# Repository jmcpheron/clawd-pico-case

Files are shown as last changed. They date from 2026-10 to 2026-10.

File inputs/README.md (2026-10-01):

# Inputs

Design files contributed by people working on this repo, kept byte-for-byte as
received. They are evidence of where a design came from, not build sources:
the parts are rebuilt in `cad/` from rows in `MEASUREMENTS.md`, and the
rebuild is checked against these files. Each file's origin, licence and
SHA-256 are logged in `PROVENANCE.md`.

| File | From | Rebuilt by |
|---|---|---|
| `2026-10-01-jason-pico-spacer.step` | Jason McPheron, Onshape, his calipers | `cad/pico_pin_spacer.py` (rows JS-*) |

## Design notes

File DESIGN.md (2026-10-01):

# Current: V3 fitted shells

J2 socket-first trial: preserve J1 exterior; roundØ3×1 deep then existing
2.01 square×2 deep, exactly as Austin requests. Print cap only before lowering
lid. Pending lowered-lid/hole-centre changes must not alter old print files.

SUPERSEDED by V3-FLAT: whole outer face atz5.1, print FACE DOWN, no supports
or raft. Austin explicitly allows greater screen depth for this trial.
Builder cad/v3_flat.py; reuse button/joystick geometry; lid-only correction.
See JOYSTICK-REVIEW.md for current status; upright plan below is historical.

Complete review and evidence: JOYSTICK-REVIEW.md. Builder cad/v3_fit.py.
Reuse V2 button caps and unchanged J1 joystick; only base/lid print.
Closed V2-aligned USB aperture, no fin; retain pry/reset. Low screen side
rails, local J1-height joystick roof and V2-height button deck. Upright lid
print intent, no supports/raft; mandatory slice review. Historical D7/D8
below are rejected designs, not the current print candidate.

# Historical V3 low-lid revision — D7/D8

Original MIT geometry from this repository's hardware measurements and
Austin's feedback. No external case geometry. Review only, no print approval.

Hard constraint: lid top is glass top +1 mm, z3.05. No joystick collar or
uniform case raise. The rejected tall draft remains saved in v3-review-1.

D7 side retaining tabs cleared5 degrees but failed16 ten-degree lid cases;
that unsuccessful experiment is saved in commit2587340.

D8 uses one rear arm/heel on the joystick cap. The heel is behind the PCB
edge, allowing downward tilt into a local interior pocket, without changing
case height. Earlier full-case4010773 lower socket/neck remain unchanged.
V2 ball diameter7 and small top print flat remain. The cap is still installed
before the lid. The rear heel's thin sections need slicer and strength review.

Button retaining wings now sit beside the switches, below the plunger tops.
The central underside contacts each plunger at measured z2.61. Outside cap
footprint and1.8 mm protrusion remain. Flat top-down printing is planned.

Keep V2-aligned closed USB port, no external lid fin, successful pry notches
and bottom access. Changes and all trial coordinates are recorded in
MEASUREMENTS.md. Required motion scenarios include the full10 degrees,
presses, both pivot assumptions and cap/base/PCB clearance. Inherited
socket/neck versus guessed metal-body collisions remain disclosed.

See reports/2026-09-25-low-lid-experiments.md. Browser review comes before
printing, and no new print artifacts have been produced for this revision.
# J1 isolated joystick test — 2026-09-25

See JOYSTICK-REVIEW.md for the complete current review packet. Original
round-lip cap plus hand-held lid gauge only; D8 rear arm rejected. J1 preserves
the selected V1 socket, has known10-degree motion failures, and is not sent
to the printer. Full-case geometry is unchanged.
## J3 / L1 trial — 2026-09-25

Widen round socket to Austin's 3.50 × 1.10 mm; keep square 2.01 × 2.00 mm
and exterior unchanged. Lower whole flat face 0.90 mm to z4.20, pocket roof
to z3.50. Existing buttons limit further lowering: 0.64 mm roof now remains.
No local boss, supports, USB fin, new base or new buttons. Lip height z2.45
is Austin's estimate for visualization, not proven seating. Iteratively find
motion limit then back off. Full details in JOYSTICK-REVIEW.md.
## L2 / J2 authorized physical trial — 2026-09-25

Move L1 upper roof down 1.00 mm, retaining roof thickness. Keep lower wall
geometry through original glass-clearance height and union translated upper
geometry; preserve contacts, mating skirt and snaps. Face z3.20, joystick
underside z2.50, button underside z2.56. Same base/buttons; exact J2 socket.
User accepts possibly unsuccessful fit; predicted overlaps remain in report,
not suppressed or counted as passes. Print face down with no supports/raft.
## L3 opening correction — 2026-09-25

L2 failed physical closure. Restore L1 thickness/height/pockets and shift only
round opening 1.00 mm toward LCD (CAD negative Y). Fill old throat crescent,
recut at new centre; retain 8 mm diameter and existing lip cavity. No base,
button or joystick changes. Print lid only, face down, supports/raft off.
## L4 alignment refinement

L3 physically overshot. New aperture centre is original X+0.30, Y-0.50:
halfway back from L3 and slightly photo-up with LCD on right. Keep diameter,
height and lip pocket unchanged. Photo-up magnitude is explicitly a trial
choice, not a calibrated measurement. Prepared lid only, not dispatched.
## S1 stronger walls / lower seam — review before printing

Austin's IMG_0834 shows exterior flexible bands and catch windows; he reports
bending during print removal. Replace these with continuous walls and blind
internal detents. Move visible seam to one-third of total height from bottom.
Make walls 3 mm by growing outward, preserving internal board clearances and
fitted control roof heights. A continuous thick perimeter/deeper walls are
intended to improve stiffness without lowering the control pockets again.

Joint uses 3 mm overlap, 1.4 mm socket wall, 0.2 mm gap, 1.4 mm tongue;
small bidirectional ramp catches allow removal without exposed flexible slots.
Minimum exterior skin at blind catches is 1.05 mm. One pry notch remains.
Actual strength, release force and cycle life require testing.

Transfer board support to two base-carried internal rails because the original
wall shelf would otherwise belong to the upper shell and obstruct assembly.
Retain USB port/reset location; extend outside cable recess to compensate for
added wall thickness. L4 opening offset retained. New matching shell pair;
does not fit old base. Interactive review requested; no printer dispatch.
## S2 closure and tactile refinement

S1 field feedback: loose vertical joint and indistinct button tops. Replace
base only: preserve body/rails/ports, swap symmetric triangular detents for
deeper catches with flat holding face, short vertical nose and insertion ramp.
Use existing lid-pocket lower edge to reduce nominal axial travel to0.04 mm;
projection0.50 consumes0.30mm socket flex and leaves0.05mm recess spare.
No claimed FDM accuracy or tested retention force. Small catch overhang needs
slice review. Keep existing lid/pry notch; no new exterior slots.

Caps retain V2 interface, gain0.50mm height and1.20mm rolled top edges to
separate finger contact areas. No change to button spacing or flange height.
Print five parts in PLA; defer PETG/colors until fit iterations finish.
## V1.0 production — final nudges

S2 passed Austin's hands-on test, so the design is frozen apart from three
0.25 mm nudges. Each one moves an opening and keeps its size, so nothing else
in the fit changes. Joystick throat: +y, away from the LCD. It uses L4's
method: fill the old throat through the roof, then cut the new one. The pocket
underneath does not move. USB-C aperture and plug recess: +z. Both stay under
the seam, so the lid needs no change there. The bottom clearance to the
modelled shell drops to 0.10 mm, which is fine because the photo shows the
real receptacle sitting high. Reset hole: -y. Each opening is refilled only
inside the original wall or floor before it is recut, and a check shows
nothing else changed. The buttons and J2 are byte-identical to the tested
parts. PETG shrinks differently from PLA, so the first PETG set is also a
fit check.
## V1.1 USB-end spacer

The v1.0 PETG test showed the stack sliding along the case, and it lines up
best pushed toward the buttons. The holes are therefore right for that
position, so the fix holds the board there and leaves every opening alone.
The USB-end stop face moves 1.0 mm inward: Austin felt about 1.2 mm of play,
and 0.2 mm is kept free so a rigid PCB cannot bind. The model predicts 0.6 mm
of play, so the real board or print differs from the model; his hands win.
The rails would block a full-width lid wall, so the stop is split in two. The
lid gets a lip between the rails that catches the LCD PCB edge; its 45° top
prints face-down with no support. The base gets end stops on top of the rails,
so the board is located before the lid goes on. The USB plug already works
with the board pushed this way, so the plug recess is unchanged.
## V1.3 short USB end (replaces the V1.1/V1.2 spacers)

The spacer added parts (a lid lip and base stops) and still needed both
halves reprinted. Moving the end wall in does the same job with less: the case
gets 0.5 mm shorter, there is no inner lip, and the USB plug sits 0.5 mm closer
to the port. The whole end is rebuilt from the moved datums, so the corners,
the tongue and socket, the rail ends (0.25 mm gap kept), the USB slot and the
plug recess all follow. Everything else is unchanged from v1.0, and a check
confirms that.
## J10 joystick set — 2026-09-29

A direction push on some devices clicks twice. The flange edge behind the push
rises into the lid underside, pivots there and drives the stem down into the
centre switch. Austin wants a joystick-only fix, so the lid is unchanged.
Four caps, numbered I-IV on top, each keep J9's socket and top and change only
what sits under the lid. I and II swap the full disc for four tabs. A tab off
the push axis rises less than the disc rim directly behind the push. I puts
them on the socket diagonals, II on the flats; the stem's turn on the board
is not measured, so one of the two lands on the diagonals. III and IV ride
0.2 lower for more room under the lid, at the risk of a stiffer press (why
J5 raised it). The model gives the tabs 2-3 degrees more tilt before the lid
is touched; the true tilt and seating are unmeasured, so the print decides.
Numerals are engraved, not raised, so the top still feels flat.
## J11 square flange — 2026-09-30

J10 failed: tabs reaching 0.6 past the hole slip through it. Austin's
direction: keep J9 and make its flange a square, thin toward the four push
directions with the corners on the diagonals. The edge behind a push is then a
flat side, which rises less than the old disc rim; the corners sit off the
push axes and still hold the cap in the hole. Two sizes (8.0 and 7.2 across the
flats) and both turns against the socket, because the stem square's turn on
the board is not measured. The pair whose flats face up/down/left/right is the
right turn. A flange that drops lower past the switch body is deferred: it
needs the body height, and it would stop the underside printing flat.
## J12 ride height on J11-III — 2026-09-30

J11-III cured the double click, but the centre press is hard to get without a
direction: the cap sits too low on the stick. J12 raises it the J5 way, with a
shallower round mouth, in four 0.1 steps (V-VIII). Riding higher gives the
press room but lifts the flange toward the lid again, so the set spans both
ends: VIII is back near J9's lid clearance in the model. Austin picks the
lowest one whose centre press is clean.
## J13 split press room from lid room — 2026-09-30

Ride height alone trades press room against lid room, and the working window
sits between VI and VII. The underside of the cap sets press room; the flange
top, where it sits under the lid, sets lid room. J13 thins the flange only
under the lid (0.24 from the hole edge out), so a cap can ride VII-high with
more lid room, and the underside still prints flat on the bed. A smaller square
can't help: its corners must reach past the hole. Round discs just past the
hole close the see-through gap the square leaves; in the model only the 8.6
disc beats VII, and it overlaps the hole by 0.3, so it may be loose. Letters
replace numerals.
## J14 stick fit on J13-O — 2026-09-30

O won J13 on a rough print. J14 prints it clean in three grip sizes around
its 1.90 square (1.85 / 1.90 / 1.95), everything else identical, so the next
test shows both whether O repeats and which grip holds best. Dots replace
letters because small engraved letters print as blobs.
## J16 hard stop and pull-out flares — 2026-09-30

J15's round mouth let the cap slide over the stem's base lip when pushed hard,
and its 0.3 overlap let a hard pull take it out of the lid. J16 cuts the square
grip all the way to the bed face, so the lip stops the cap, and adds four
narrow thin flares on the diagonals. The flares must stay short and thin:
material far out under the lid is what gets caught when the cap tips (the
8.6 disc edge slides into the hole instead), so the chosen flares keep VI's
lid room in the model while reaching 0.8 past the hole.
## J17 gradient on J16 — 2026-09-30

Bigger tabs hold the cap in the lid but get caught under the lid when it tips;
a shallower hole gives a better centre press but lifts the flange toward the
lid. Both push the same way, so J17 walks one path from J16 (tested clean) to
a cap the model is sure double-clicks, in five steps. Austin picks the step
with the best hold and press that still clicks clean.
## Jason's Pico pin spacer and its I2C variant — 2026-10-01

Jason's spacer is a 1.0 plate between the header rows with square-holed tabs
over chosen pins. It is rebuilt from rows rather than imported, so every
number traces to MEASUREMENTS, and the rebuild is checked equal to his STEP.

- On the datasheet grid: his caliper positions (17.70 × 48.20) are close to
  the 2.54 grid (17.78 × 48.26). Snapping keeps every added pin exactly on
  the pin it is meant for, rather than letting caliper rounding add up.
- Pins 6 and 7 share one tab: they are 2.54 apart, less than a 3.3 tab.
- Pins 36, 38 and 40 keep separate tabs, so pins 37 and 39 pass through the
  1.78 gaps. Those junction fillets are r 0.8, because two r 1.0 fillets
  need 2.0.
- With the extra tabs the part only fits one way round, but it would still
  slide onto pins backwards or upside down. A dot by pin 1 and an arrow to
  the USB end on the top face show which way it goes.
- Kept as his: the sharp corner where the plate end meets a corner tab, the
  r 1.0 tab corners, 1.3 square holes, 1.0 thickness.

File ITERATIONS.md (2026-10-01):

# Design and print iteration register

## J2 stepped joystick socket — 2026-09-25

cap only, unchanged J1 exterior, deeper round-to-square bore per Austin.
Source cad/joystick_j2.py; STL stl/joystick-j2; checks renders/joystick-j2.
Physical seating trial precedes lowered lid/hole-centre adjustment.

## V3-FLAT — 2026-09-25

Correct upright-print failure: uniform outer lid facez5.1, face-down STL,
supports/raft OFF,699 checks. Existing buttons still1.3 mm proud. Lid only;
no cap/base reprint. Sources cad/v3_flat.py, artifacts stl/v3-flat and
renders/v3-flat; print log prints/2026-09-25-v3-flat.md. Austin explicitly
allows whole-face height increase for fitting. Upright revision preserved.

Every saved design revision belongs in git with its original CAD, generated
STL/STEP files, rationale, evidence and validation results. Print jobs must
reference an immutable commit/tag and record slicer settings, artifact hashes,
delivery/start status and the eventual fit result. Never replace a failed
version's history with a corrected version or describe a queued job as printed.

## Historical designs (2026-09-24)

## Current: V3 fitted shells — 2026-09-25

Builder cad/v3_fit.py; files stl/v3-fit and renders/v3-fit. Only two shells.
V2 buttons and J1 cap reused without change.697 required checks, inherited
J1 motion uncertainty retained. JOYSTICK-REVIEW.md is the single review
handoff. Dispatch recorded in prints/2026-09-25-v3-fit.md. Upright lid needs
operator slice review before start; no supports/raft authorized.

## Historical designs (2026-09-24, continued)

| Commit | Iteration / change | Print evidence |
|---|---|---|
| `30ecec9` | First original board proxies, snap case, caps and viewer | No recorded result |
| `9260716` | Correct USB orientation to joystick end | No recorded result |
| `f178c19` | Square flanged button caps and individual holes | No recorded result |
| `6469436` | Print-oriented exports | Test 1 source; request logged at `752fcb4` |
| `f3eb689` | Thicker tongue, Ø10.5 joystick opening | Intermediate lid revision; see historical REPORT.md |
| `29e74e1` | Working snap windows/wedges, corner and documentation audit | Intermediate corrected geometry |
| `4010773` | Test 2: Ø12 joystick opening, neck/disc cap, USB envelope/recess, two pads | Request logged at `28f6932`; fit result pending |
| `prototype-r4` tag | R4: mating gap/flexible bands, USB insertion channel/fin, sloped shelves, four pads, cap clearance fixes, 171 geometric checks | Test 3 submitted to HTTP inbox; IDs and pending result in its log |

Setup, measurement and report commits are also preserved in the full git
history. This register identifies meaningful design states; it does not imply
that every intermediate state was physically printed. Earlier unsaved edits
cannot be reconstructed as separate revisions.

## V1 feedback / R5 checkpoint

Austin identifies the photographed first-principles case as V1; its exact
print commit is not established. Three photos and five requested changes
are saved in `prints/2026-09-24-v1-feedback.md`.

Tag `r5-wip-joystick-pry`: captive ball joystick and two pry notches;
273 CAD checks pass. Not submitted; not ready to print. USB-C and
rectangular/taller buttons and bottom button access remain pending.
Earlier history is preserved.

## Artifact reproducibility

## V2 print candidate / completed R5

Tag `prototype-v2`: completes all five V1 requests. Adds scan-derived bottom
button hole, rectangular/taller buttons, higher/tighter USB-C; retains
checkpoint joystick and notches. Includes measurement script/overlay,
mesh degenerate-facet removal, geometry checks, STL/STEP, preview and hashes.
Print status and eventual results: `prints/2026-09-24-v2.md`. V2 is not a
physical-fit certification. Older WIP remains saved under its own tag.

## Hash records

## V3 browser review — 2026-09-25

Tag `v3-review-1`: original4010773 lower joystick interface, V2-sized ball
with printing flat, tapered inside lip, uniformly flat lid4 mm higher, longer
button stems, closed USB base port without fin. V2 USB alignment retained.
Browser viewer includes orbit, explode, part toggles and shell transparency.
See `reports/2026-09-25-v3-review.md`; requires Austin's approval before print.
No printer submission. Geometry/tag are a review checkpoint, not print success.

## Hash records (all revisions)

## V3 low-lid revisions

- `2587340`: D7 side-tab experiment. Screen recess1 mm;16 required
  ten-degree lid-motion cases failed. Saved explicitly as failed, not printed.
- `v3-review-2`: D8 rear retaining tab and internal rear-wall pocket. Keeps
  screen recess1 mm and earlier socket; lowers button retaining wings.
  Review viewer only: no replacement print files or printer request.
  See `reports/2026-09-25-low-lid-experiments.md` and `renders/v3-low/`.

The older tall `v3-review-1` and all failed versions remain in Git history.

2026-09-25 physical result: Austin reports V2 joystick socket failure and
support-related button-hole problems. Pry access, bottom access alignment
and rectangular cap shape worked. `reports/2026-09-25-v2-review.md` records
the results and flat-lid, support-free correction goals. V2 tag unchanged;
this is a documentation-only review, not a new printable revision.

- Source and output SHA-256 hashes: `stl/manifest.json`.
- Geometric checks and source hashes: `renders/validation.json`.
- Reasoning and limitations: `DESIGN.md`, `REPORT.md`, `MEASUREMENTS.md`.
- Clean-room input record: append-only `PROVENANCE.md`.
- Physical trial: `prints/2026-09-24-test3-r4.md`.

The generated manifest's `git` field identifies the pre-commit parent with
`-modified`, because artifacts were built before committing. Its source
hashes identify the exact CAD in the R4 tag; do not rebuild merely to change
that label. Future geometry changes get a new commit and a new iteration tag.
Printer-profile or status changes get separate commits so the geometry tag
stays fixed. Keep printer credentials and machine-local configuration out of
this public repository.
# J1 isolated round-lip review — 2026-09-25

Source cad/joystick_test.py; outputs stl/joystick-j1 and renders/joystick-j1.
Complete handoff: JOYSTICK-REVIEW.md. Two test parts, known motion failures,
review before printing. Historical whole-case files remain unchanged.
## J3 / L1 — 2026-09-25

J2 round hole too tight per Austin. J3: round 3.50 × 1.10 mm, deeper square
unchanged. L1: flat lid face 0.90 mm lower, existing base/buttons retained.
Original source cad/j3_low_lid.py; isolated artifacts stl/j3-low-lid and
renders/j3-low-lid. 18 checks pass. Physical travel and fit pending.
Only lid and joystick authorized; supports/raft off. See JOYSTICK-REVIEW.md
and prints/2026-09-25-j3-low-lid.md for full handoff and dispatch.
### J3 / L1 pre-dispatch correction

Review caught the initial top-trimming box also truncating the skirt.
Corrected its lower bound to preserve the full skirt; strengthened validation
to compare both material differences and minimum Z. Initial 8b0fc03 artifacts
were never dispatched. Only the corrected full-skirt revision is printable.
## J2 restore / lower another 1.50 mm — preflight only

User rejects J3 socket, selects J2 unchanged. Requested face z2.70 conflicts
with existing button pocket roof z3.56. No geometry or print produced; details
and required scope decision recorded in JOYSTICK-REVIEW.md. Prior print files
unchanged. Await choice on retention redesign versus height target.
## L2 / exact J2 — one-millimeter physical trial

Austin supersedes 1.50 mm with 1.00 mm and explicitly authorizes printing
despite fit uncertainty. Roof translated, not shaved. J2 byte-identical.
Seven structural checks pass; hat/button overlaps remain diagnostic warnings.
Files: cad/l2_j2_trial.py, stl/l2-j2/, renders/l2-j2/. Full handoff in
JOYSTICK-REVIEW.md; dispatch in prints/2026-09-25-l2-j2.md.
## L3 — restore L1 height and shift round hole toward LCD

Austin confirms L2 cannot close with caps installed. Revert height to L1 and
move 8 mm opening 1.00 mm toward LCD using his new photos/direction. Pocket
and all other L1 geometry unchanged. Lid only print. Isolated original source
cad/l3_shifted_hole.py and stl/renders/l3-shifted-hole artifacts.
## L4 — halfway back plus photo-up, not yet printed

L3 feedback/photos show overshoot. Aperture moves +0.50 Y and +0.30 X from
L3, leaving centre (13.4671,45.6292). Isolated source cad/l4_alignment.py,
STL and viewer under l4-alignment. All prior versions preserved. No dispatch.
## S1 — stronger matching shells with 2:1 visible height split

User requests seam lower, smooth stronger sides, one pry notch, L4 alignment,
and interactive rendering before print. Original cad/s1_strong_shell.py.
Artifacts stl/s1-strong-shell and renders/s1-strong-shell. 21 geometry checks
and browser smoke test pass. Joint force/strength/physical assembly untested.
New pair required; reuse J2/buttons. No printing until review. Full handoff in
JOYSTICK-REVIEW.md, including internal rails and exact wall/joint dimensions.
## S1 full-case print approval / packaging

Austin approves reviewed S1 and requests joystick plus buttons too. No shell
geometry change. Package seven pieces with lid face down, base floor down,
J2 and V2 buttons flange down. cad/s1_full_plate.py exports individual parts
and one plate; byte-check shells/J2 against original reviewed exports.
Print log prints/2026-09-25-s1-full-case.md. Preserve original review artifacts.
## S2 — base-only closure fix and rounded buttons

Physical S1 nearly works but drops roughly0.25mm and opens too easily. New
base catch shape targets minimal axial play using existing S1 lid pockets.
Four button caps have tops0.50mm taller, rounded radius1.20, same interfaces.
Original isolated cad/s2_tight_base.py, stl/renders/s2-tight-base. 36 checks
pass. Reuse S1 lid and J2; physical force and tactile test pending. IMG_0840
archives assembled S1 baseline, duplicate uploads stored once with hashes.
## V1.0 — first production release

The earlier V1/V2/V3, R, J, L and S rounds were development prototypes (0.x).
S2 passed Austin's test. V1.0 = S1 lid + S2 base + S2 buttons + J2, plus three
0.25 mm nudges: the joystick hole moves toward USB-C, the USB-C opening moves
up, and the reset hole moves toward the centre. Source: cad/v1_production.py.
Outputs: stl/v1.0 and renders/v1.0, with 35 checks passing and the browser
viewer tested. Not printed in PLA, at Austin's request; the next prints are in
PETG. Photos: prints/v1.0-photos. Tag: v1.0.
## V1.1 — USB-end spacer

PETG v1.0 works well, but the board slides about 1.2 mm along the case.
V1.1 = v1.0 plus a 1.0 mm stop at the USB end: a lid lip between the rails
and base stops on the rails. The openings are unchanged. Source:
cad/v1_1_spacer.py. Outputs: stl/v1.1 and renders/v1.1, with 16 checks
passing and the viewer tested. The caps are unchanged; reuse the v1.0 caps.
## V1.2 — half spacer

The v1.1 1.0 mm spacer was too big (the board would not sit flush). V1.2 is
the same design with 0.5 mm. Source: cad/v1_2_half_spacer.py. Outputs:
stl/v1.2 and renders/v1.2. All checks pass.
## V1.3 — USB end wall 0.5 mm in, no spacer

This replaces the V1.1/V1.2 spacer trials. It is v1.0 with the USB-C end wall
0.5 mm inward on the lid and base; the case is 58.60 mm long. Source:
cad/v1_3_short_end.py. Outputs: stl/v1.3 and renders/v1.3, with 19 checks
passing. The caps are unchanged.
## Current best: v1.3 (2026-09-26)

v1.3 passed Austin's test: nothing rattles, and everything clicks.
`cad/current.py` copies it to `stl/current/` (lid, base, joystick, button,
full-set plate) at stable paths, and it is tagged v1.3. For future winners,
update CURRENT/PARTS and rerun.
## V1.4 — rounded top and LCD window edges (review only)

v1.3 with a 1.5 mm top-perimeter fillet and a 0.7 mm LCD-window fillet on the
lid. The fit is unchanged, and the base and caps are the same as v1.3.
Source: cad/v1_4_rounded.py. Outputs: stl/v1.4 and renders/v1.4, with 8
checks passing and the viewer tested. Not printed. Face-down printing puts
both roundings at the bed, so a slice check is needed.
V1.4 review 3: the top edge is rounded 3.0 mm and the window 1.2 mm (review 1:
1.5 and 0.7). Base check: byte-identical to the v1.3 base.
V1.4 review 4: the window is 1.0 mm smaller on each side (covering 0.6 mm of
the glass border) with a rounded bezel 0.3 mm above the glass. Base unchanged.
J4 joystick (v1.4): J2 with a 5 mm flat top, so pressing in is easier. It is
1.05 mm shorter, and the socket and tilt are unchanged. File:
stl/v1.4/joystick.stl. Not printed.
J4 review 2: the flat top becomes a hat (5.5 mm waist, 45° flare, 7 mm disc,
about 6 mm flat), at the same height as J2. Not printed.
J4 review 3: a 7.4 mm half ball with a flat top all the way across (the hat
version was dropped). It passes the 8 mm hole with 0.3 mm each side, and no
new tilt contact versus J2. Not printed.
J5 (v1.4 joystick): J4's outside with the socket narrowing sooner, so the cap
rides higher and leaves room to press in. Test pair:
stl/v1.4/joystick-j5-lift-0.3.stl (viewer default) and -lift-0.5.stl. Not
printed.
J6 (v1.4 joystick test set): a tighter socket (A 1.95, B 1.90) and a thumb
dish (C), so pressing in gives a clean centre click. The flange notches 1/2/3
mark A/B/C. The plate is stl/v1.4/joystick-j6/joystick-j6-abc-plate.stl.
J7 (v1.4 joystick test set): J6 A/B/C with a self-supporting socket, so no
bridges or ledges inside. The plate is
stl/v1.4/joystick-j7/joystick-j7-abc-plate.stl.
V1.4 lid + crush ribs: 12 vertical ribs grip the existing v1.3/v1.4 base by
0.15 mm, so no rattle and a firmer hold. Lid only.
## V1.5 — lid 0.5 mm taller (v1.4 + ribs + J9)

The joystick flange gets room to tip without the roof pressing the centre
click. Taller button caps come with it. Base unchanged. Source:
cad/v1_5_tall.py. Outputs: stl/v1.5 (lid, button, J9) and renders/v1.5,
with all checks passing. Not printed.
## Current best: v1.5 (2026-09-26)

v1.5 lid + v1.3 base + J9 joystick + original S2 buttons, in stl/current/,
tagged v1.5.
## V1.6 — v1.5 with a print-friendly top edge

A 45° band starts the top curve so the face-down print has no droop line.
Lid only. Source: cad/v1_6_bevel.py. Output: stl/v1.6/lid-face-down.stl.
Not printed; current stays v1.5 until it is tested.
## V1.7 — locking case (new base + lid)

6 catches hooking 0.5 mm, a gentle closing ramp, and a tool/thumbnail slot
only in the base. The v1.7 lid does not fit older bases, and v1.7 bases do
not fit older lids. Source: cad/v1_7_lock.py. Outputs: stl/v1.7 and
renders/v1.7. Not printed.
## J10-J14 — joystick double click (2026-09-29/30)

Direction pushes also clicked the centre: the flange edge behind the push rose
into the lid. J10 tabs fell through the hole; J11 square flange cured the
double click; J12 found the ride height between VI and VII; J13 thinned the
flange under the lid (O, round 8.6, won); J14 tried three grips on O.
## Current best: v1.5 + J14-2 (2026-09-30)

v1.5 lid + v1.3 base + J14-2 joystick + original S2 buttons, in stl/current/.
Austin: J14-2 "is the one ... stays on the thing the best ... you push the
button down the best".
## Current best: v1.7 + J14-2 (2026-09-30)

v1.7 lid + v1.7 base + J14-2 joystick + original S2 buttons, in stl/current/.
The v1.7 pair passed on 2026-09-27 and Austin batch-printed 24 of each
(print Mac log); the repo never recorded it, so current said v1.5 until now.
## J15-J22 and current best: v1.7 + J22 (2026-09-30)

J15 slid over the stick's collar and pulled out; J16 squared the hole and
added tabs; J17 grew the tabs; J18-J19 swept the hole depth because the cap
bottom pressed the collar (all five switches); J20-J21 brought back a wide
mouth over the collar; J21-1 (1.9 deep) won and, with a flat top, is J22.
## Pico pin spacer (Jason) + I2C variant (2026-10-01)

Jason's own spacer (inputs/2026-10-01-jason-pico-spacer.step) rebuilt in
cad/pico_pin_spacer.py and checked equal to his file, then built on the
datasheet pin grid in two versions: corners (pins 1, 20, 21, 40) and i2c
(+ 6/GP4, 7/GP5, 36/3V3, 38/GND, pin-1 dot and USB arrow). Outputs:
stl/pico-spacer, renders/pico-spacer (STEP for Onshape, top-view.svg,
validation). 16 checks pass. Fits the v1.7 case footprint (0.17 to the rails);
needs 1.0 free under the LCD sockets. Not printed; stl/current unchanged.

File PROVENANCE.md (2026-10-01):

# Provenance log

Append-only. Newest at the bottom. Every design input, every session that
touched geometry, and what that session had seen.

## 2026-09-19. Phase 0. Repo created.

- By: Claude (Fable 5.1), session started in `~/picowallet`, on Austin's
  instruction, after he asked how to make a sellable case.
- Contamination statement: this session had, earlier the same day, read the
  picowallet `case/` notes and memory referring to the Zez0000 and Plass
  designs and their derivatives, and had opened the MakerWorld listing page
  for model 3230142 to read its license. It did not open the STLs in this
  session but has their derived measurements in its notes.
- What it wrote: `README.md`, `LICENSE`, `CLAUDE.md`, `PROCESS.md`,
  `SOURCES.md`, `MEASUREMENTS.md`, this file. No `scad/`. No `stl/`.
- Dimensions written: only the Raspberry Pi Pico 2 W rows P1 to P10 in
  `MEASUREMENTS.md`, all from the public Pico datasheet mechanical drawing,
  all marked "confirm cal". No LCD board, screen, button, joystick, stack or
  case dimensions were written.
- Decision: all geometry will be produced by fresh sessions started in this
  directory that have not loaded `~/picowallet` or its memory.
- Austin has handled and seen the earlier printed cases. That is the normal
  position of anyone designing a product in a category that already has
  products. The rule for him is the same as for the agents: measure the
  hardware, do not open the other files, write choices down.

## 2026-09-20. Method research.

- By: the same Claude session as Phase 0 (still contaminated, still no geometry).
- Read: Raspberry Pi Pico series documentation page and the Pico 2 STEP link;
  the Waveshare Pico-LCD-1.3 wiki Resources list and schematic PDF (links and
  part labels only, no case content); general 3D scanner and flatbed
  reverse-engineering articles. Did not open any case design.
- Wrote: `research/scanning.md`. Switched the plan from OpenSCAD to build123d
  so the official Pico 2 STEP can be imported. Added the STEP and the
  schematic to allowed sources. Nothing measured, nothing drawn.

## 2026-09-24. Phase 1 measuring and first geometry.

- By: Claude (Opus 5.5), one session started in this directory. It did not
  load `~/picowallet` or its memory, did not open any forbidden path in
  `CLAUDE.md`, and made no web search or web fetch (checked against the
  session transcript on 2026-09-24). Its only contact with `~/picowallet`
  was one `ls -d` checking that the directory exists.
- Inputs used, all logged in `MEASUREMENTS.md` with row IDs:
  - Flatbed scan 01 of Austin's boards, 600 dpi, scale from a steel rule in
    the same scan (`measurements/2026-09-24-scan-01-*`). Our own image.
  - Caliper readings taken by Austin on the bench, read aloud, one iPad
    camera frame saved per reading (`measurements/2026-09-24-cal-*.jpg`).
  - Austin's statements: USB-C at the joystick end (A3); PINK board only;
    snap fit; square caps with a web and a lip.
  - Datasheet: header row spacing 17.78 = 7 x 2.54 (P10), the standard Pico
    pinout, used only to place the sockets and the Pico in the render.
- No third-party geometry. Tools only: build123d (Apache-2.0) generates the
  shapes; three.js (MIT) is loaded from cdnjs by the viewer and not copied in.
- Wrote: `cad/params.py`, `cad/model.py`, `cad/build.py`, `stl/`,
  `renders/viewer.html`, `REPORT.md`, first test print drops.

## 2026-09-24. Independent revision R4, Codex.

- Session started in this repository at Austin's request to critically review
  all measurements and correct or redesign the case. Read this repository's
  documents, code, scan analysis, overlay and caliper photographs. No other
  case listings, geometry, picowallet files or memory were opened. No imported
  third-party geometry. Existing MIT license retained.
- Inputs: the recorded caliper values and scan01 already listed above.
  Photo review identifies evidence limitations; it does not silently replace
  Austin's readings with uncertain image readings. New derived coordinate
  rows and explicit design/verification assumptions are in MEASUREMENTS.md.
- Original engineering changes: clearance between halves, slotted lid snap
  arms, sloped shelf undersides, USB insertion channel with lid closure,
  four PCB hold-down pads, narrower button flanges, and joystick fit samples.
  Choices and remaining physical tests are documented in DESIGN.md/REPORT.md.

## 2026-09-24. R5 captive joystick, Codex.

- Input: Austin's direct feedback from the first physical print. The joystick
  cap must attach to the board before the lid; a lower lip retains it inside
  the case, with a shaft and ball outside. R4's post-lid cap is rejected.
- No external case geometry, photographs, or measurements consulted. Existing
  hardware rows retained; new flange/ball/collar dimensions are original design
  choices D5-JOY. Joystick motion is still an assumed verification envelope.
- Sent a hold request for R4 via the already authorized print inbox workflow.
  Preserve R4 tag/history. R5 changes joystick cap and lid only, with assembly,
  retention and motion checks, matching documentation and rebuilt outputs.
- Additional direct feedback: the first printed case is difficult to open;
  Austin requests a tool notch. Add two original shallow seam notches
  (D5-PRY), preserving the flexible latch bands and underlying wall.

## 2026-09-24. V1 physical feedback and photos, Codex.

- Austin explicitly identifies the photographed case as V1, made from first
  principles without another licensed case. Input is his own printed case,
  not an external enclosure reference. Repo MIT license is unchanged.
- Viewed his uploads paste-f2819d95-IMG_0801.jpg (joystick),
  paste-f925a63a-IMG_0800.jpg (buttons), paste-42cd1b6f-IMG_0799.jpg (USB).
  Saved unchanged in prints/v1-feedback/. No dimensions inferred from the
  perspective photos; no other case sources consulted.
- Additional requested changes: taller/wider rectangular buttons with
  smaller top/bottom lips; smaller USB opening shifted toward lid; bottom
  tool-access hole over pink board button. Button identity, coordinates and
  pad size are not established. These three changes remain pending.
- Saved feedback separately from the R5 joystick/pry CAD checkpoint.
  Physical V1's exact source commit is not established. Preserve all earlier
  commits and tags; do not label the partial draft as ready to print.

## 2026-09-24. V2 candidate from existing scan, Codex.

- Austin explicitly authorizes making a good estimate from the existing pink
  board scan, iterating, completing the next version and sending to printer.
- Revisited scan01 and its original measurement script. Detected the pale
  board button at crop-local (294.0667,409.7847), centre-relative u=13.4370,
  v=-3.2868 mm. Opposite-facing component side requires lateral reflection
  into the LCD-front coordinate frame. Recorded PINK-BTN-SCAN and D5-ACCESS.
- V1 USB photo supports the higher existing A1 placement rather than P15's
  lower placement; selected A1 for shell/aperture but kept conservative
  floor depth. Recorded original button/access/USB trial choices before CAD.
- No third-party case geometry viewed or imported. V2 is the next physical
  print candidate; internal CAD revision remains R5 after its saved checkpoint.

## 2026-09-25. V2 physical review, Codex.

- Input: Austin's direct physical feedback. Pry feature, bottom board-button
  hole alignment and rectangular cap shape worked. V2 joystick does not fit
  PCB stick; raised collar and support layer caused problems at button holes.
  Earlier joystick fit and movement were good.
- Requested correction goals: preserve successful features and earlier
  joystick interface/movement; add internal lip and ball passing through
  opening; restore flat lid, no raised case or problematic supports.
- Austin requested documentation first. Added review/handoff and status
  notices only. No geometry changes, external case references, new hardware
  dimensions or printer actions. Specific socket failure cause and actual
  slicer support construction remain unverified.

## 2026-09-25. V3 browser-review design, Codex.

- Austin reports V2 USB opening aligns but rejects the lid fin/tab and its
  gaps. Restore closed base port style with V2 alignment. Keep working pry
  notches, bottom access and rectangular caps.
- Requests earlier joystick bottom/interface and V2 ball, captured inside a
  flat lid; permits uniform extra lid height and correspondingly taller caps.
  No support layer or raised local collar. Requests interactive browser
  rendering and approval before printing; no printer action authorized now.
- Inspected only this repository's original commits6469436 and4010773.
  Both sockets2.01 and roof5.30 versus V2 socket1.91 and roof5.00. Select
  full-case4010773 lower geometry as explicit provisional V1 baseline;
  exact physical cap source not independently confirmed. No external models.
- Original tapered flange and small ball-top print flat added for support-
  avoiding inverted cap printing; choices logged D6, not hardware readings.

- Final V3 review: flat top4.0 mm higher, original full-case lower shape
  matched by CAD difference checks. Smaller pocket and screen-side web keep
  the joystick relief from opening into the display well. Closed-port
  USB-first assembly checked at19 separate-Pico poses; physical test pending.
- Required geometry checks206 passed;48 intersections with guessed joystick
  body retained as unresolved sensitivity diagnostics rather than changing
  the reported-working earlier neck to satisfy an unmeasured proxy.
- Browser controls tested in local Chromium. Served only renders/ on LAN
  port8765 for user review. No printer interaction. V3 approval remains pending.

## 2026-09-25. Low-lid V3 revision in progress, Codex.

- Austin rejects deep screen recess and requires top at most1 mm above glass.
  Explicitly asks to proceed now. No additional outside geometry consulted.
- D7 tests original side-arm retention around joystick body, retaining earlier
  socket. Button underside relief allows retaining wings below plunger top.
  Measurements unchanged; these are trial constructions requiring checks.
- Five-degree motion is a chosen trial, not established hardware travel;
  retain larger-angle failures explicitly. No print authorized or requested.

- D7 side tabs failed16 ten-degree lid-motion cases; saved as failed
  checkpoint. D8 tests one rear tab beyond PCB edge, using that available
  space rather than adding lid height. Original profile/pocket recorded
  before modelling. No new hardware measurements or outside designs.

- D8 refinement shifts/reprofiles the rear heel and pocket, preserving the
  original lower socket. A small PCB interference in one10-degree pressed
  pose prompted extra relief at the heel's lower edge; full original
  10-degree lid scenarios remain required, not weakened to get a pass.
- Added cap/base, cap/PCB and new rear-arm/fixed-hardware motion checks.
  Button wings are lowered beside switch bodies to retain the1 mm screen
  recess; plunger contact height and outside rectangular shape retained.
- Dedicated review builder updates browser files only; old print artifacts
  are untouched and explicitly labelled obsolete for this geometry.

- Final D8 review:495 required checks pass, including the full10-degree
  lid/base/PCB scenarios and new-arm versus fixed hardware. Inherited48
  guessed-body/neck intersections remain unresolved. Browser render and
  interactions tested; source and listed output hashes verified. No print
  artifacts generated, no printer action. Slicing, thin-junction strength
  and actual hardware movement still need verification after review.

## 2026-09-25. J1 isolated round-lip fit test, Codex.

- Austin supplied IMG_0810, IMG_0811 and IMG_0812 as side photos of his
  hardware in this ongoing fit discussion. Used qualitatively only: body
  and screen tops look similar; perspective photos are not caliper readings.
- Austin rejected D8 rear arm and rectangular opening. Requests ball through
  round hole, wider circular lip underneath, original socket, small test only.
- Latest instruction: prepare CAD viewer, STL and review note for Claude Code.
  No printing in this turn. No outside geometry used; original MIT design.
- J1 dimensions below are explicit design trials, not new measurements.

## 2026-09-25. J1 physical feedback, Codex.

- Austin supplies IMG_0814 showing his printed J1 cap/gauge on his board.
  Reports full motion when hand-held, but gauge too flimsy for confidence.
  No numerical measurement inferred from photo. Original user fit evidence.
- Requests actual lid for existing printed base, retaining unchanged J1 cap.
  Base revision unresolved; no outside designs consulted or geometry changed.

## 2026-09-25. V3 fitted shell, Codex.

- Austin resolves scope: new base with closed V1-style USB aperture at V2's
  working USB position/size, no USB lid fin; new complete lid using existing
  V2 buttons and unchanged physically tested J1 joystick. Explicitly asks
  to send only these two shell parts. Retain pry and bottom access features.
- Inputs: own prototype-v2 source and parameters, current own base/snap
  geometry, J1 cap/gauge, and Austin's reported free hand-held movement.
  No third-party geometry, no new measured dimensions. Original MIT work.
- Lid screen rim remains z3.05; local joystick roof copies J1 z4.4..5.1,
  button region copies V2 z4.6. Upright lid printing proposed to avoid the
  previous raised-top/support-layer failure; operator must review bridges
  and overhangs, and hold rather than add supports or a raft.

## 2026-09-25. V3 flat-face correction, Codex.

- Austin explicitly rejects upright lid printing. Authorizes raising the
  entire face to the joystick's required height for this fit trial, face-down
  with NO supports. Requests immediate print after confirming instructions.
- Keep underside retention at J1 z4.4; entire outer face z5.1. Reuse existing
  base, buttons and joystick. No new hardware measurements or outside inputs.
- This explicitly supersedes the prior1 mm screen-depth constraint for this
  iteration. Button protrusion reduces .5 mm to1.3 mm with unchanged caps.

## 2026-09-25. Matching V3 base print request, Codex.

- Austin reports flat lid looks great and requests matching V3 base.
  Reused unchanged existing base mesh; no new measurements or geometry.
  User report confirms lid print, not yet assembled snap/joystick fit.

## 2026-09-25. J2 stepped socket, Codex.

- Austin supplies his hardware photos IMG_0822..IMG_0827, requesting lower
  cap seating, eventually lower flat lid and a small hole-centre correction.
  Photos show round stem collar below square shaft. Caliper display3.32 mm
  is visible but feature identification remains unconfirmed, not substituted
  for the explicitly requested trial diameter.
- Austin reports collar height less than1 mm, explicitly specifies socket:
  circleØ3 mm for first1 mm, existing square for next2 mm. Existing square
  is2.01 mm across flats. No added diameter allowance silently applied.
- Austin offers printing just the joystick first. Selected this scoped fit
  trial: unchanged outer J1 cap, deeper stepped cavity, no lid/base edits.
  All geometry original from this repository; no external cases consulted.

## 2026-09-25. V3 record photos, Claude (Opus 5.5).

- Austin supplies IMG_0814, IMG_0817, IMG_0822, IMG_0827 "for the record
  books" while working on V3, and asks that the whole process be documented
  from first principles so the design ships MIT with no non-commercial
  licence entanglement.
- Saved byte-identical to `prints/v3-photos/` with hashes and a per-photo
  description. Austin's own photos of this repo's own prints and his own
  boards; MIT with the repo. No third-party design in any frame.
- Record only: no dimension taken from these photos; nothing in `cad/`
  changed. This session opened no forbidden source and no picowallet file.
### 2026-09-25 — J3 / lowered flat lid trial

Austin's own J2 print feedback and two IMG_0828 photos (upload prefixes
961919fc and 583f9050): round socket too tight; request diameter 3.5 mm,
depth 1.1 mm, retain deeper square. Lip estimated 0.4 mm above glass.
Authorized printing a new lid and joystick together and progressively lowering
the lid until motion restricts, then backing off. Photos inspected directly;
not calibrated measurements. Codex input; user-owned hardware/photos, no
third-party case geometry. Original design choices below are trial values.
## 2026-09-25 — J2 restore / further 1.5 mm lowering request

Austin reports J3 socket failed; selects immediately preceding J2 unchanged.
Reports roughly 1.5 mm available joystick clearance and authorizes lowering
latest lid by 1.5 mm and printing lid plus J2. Input is his own physical fit
feedback. Codex inspected only original repository sources. No third-party
geometry. Preflight finds existing button retention incompatible with requested
uniform height; no geometry modified or print submitted pending direction.
## 2026-09-25 — L2 one-millimeter roof translation, authorized fit trial

Austin changes the reduction to 1.00 mm and explicitly accepts a possibly
unsuccessful physical fit: keep roof thickness, move it down, print it.
Reuse unchanged J2 joystick, same base/buttons. Source: own printed hardware
feedback in this conversation. Codex uses only original repository geometry;
no external cases. CAD interference is reported, not treated as fit success.
## 2026-09-25 — L3 hole alignment / restore L1 height

Austin reports L2 cannot close with joystick/buttons installed. Requests
previous L1 height restored and hole moved at least 1 mm toward LCD; print
lid only. Own photos IMG_0831/0830/0829 (upload prefixes f4ab2501, 428b66fa,
f0156714) inspected directly. Stem appears LCD-ward of opening centre.
Use explicitly requested 1.00 mm, not a calibrated measurement from photos.
Codex uses original repository CAD only; no third-party case access.
## 2026-09-25 — L4 halfway-back alignment

Austin identifies own IMG_0832 as previous and IMG_0833 as latest L3;
latest opening overshoots, asks halfway back and slightly up. Photos inspected
directly (upload prefixes d7fdddb0, f938ec3c). Choose +0.50 CAD Y from L3,
and +0.30 CAD X (photo up with LCD on right). Lateral amount is an original
trial choice, not a calibrated photo measurement. No third-party geometry.
## 2026-09-25 — S1 strong shell / lower seam

Austin reports lid bends during removal from print plate; own IMG_0834 shows
side clip slots/windows and pry cutout. Requests stronger case/joint, no side
slots, exactly one pry notch, visible upper shell about two-thirds and base
one-third. Retain latest L4 joystick alignment. Codex inspected own photo and
original repository CAD only. New wall/joint dimensions are original design
choices, not hardware measurements. No third-party geometry introduced.
## 2026-09-25 — S1 full-set print approval

Austin approves interactive S1 review and explicitly requests immediate full
case print including joystick/buttons. Package unchanged S1 shells, exact J2
joystick and existing V2 buttons: seven parts total. No geometry changes.
Codex uses HTTP inbox skill; no credentials or private endpoints in repo.
## 2026-09-25 — S1 history photograph and evidence audit

Austin supplies his own IMG_0839 as a historical photo and requests saving to
GitHub, then auditing the development/licensing record. Saved public copy in
prints/s1-photos with EXIF/Photoshop metadata removed losslessly; decoded
pixels identical, original/public hashes recorded, original upload untouched.
Shows shells and five caps on printer bed; not a measurement or fit result.
Codex consulted this repository and official general copyright/MIT/patent
references only, not forbidden case sources or other case designs. Audit is
an evidence assessment, not a comparative design review or legal clearance.
## 2026-09-25 — S2 tighter base and rounded buttons

Austin reports S1 nearly fits, but base hangs roughly 0.25 mm when held by
lid and opens too easily. Buttons feel too close/indistinct. Requests stronger
flush closure, preferably reprint only one half, and slightly taller rounded
button tops, another print iteration in PLA before PETG/color experiments.
Inputs are his physical test feedback, not new caliper measurements. Codex
uses original S1 and V2 geometry only; no third-party cases. S2 changes base
catches and button tops while preserving S1 lid and J2 joystick.
## 2026-09-25 — assembled S1 album photo

Austin supplies own IMG_0840 twice (56146ab1 and fed322ed upload prefixes).
SHA256 confirms identical originals. Save one metadata-stripped public copy
in prints/s1-photos with original/public hashes and unchanged pixel check.
Image shows assembled case; no dimension derived. Records S1 physical
baseline before tighter-base/rounded-button S2, not an S2 test result.
## 2026-09-25 — v1.0 production release

Austin tested the printed S2 base and buttons with the S1 lid and J2 joystick
and said "This works." He asked for three final nudges of about 0.25 mm each
and said not to print them in PLA. He asked to save the result as version 1.0,
the first production version, under MIT, before printing sets in PETG.
- Joystick hole: 0.25 mm toward the USB-C end, away from the LCD.
- Reset hole in the base: 0.25 mm away from the USB-C end, toward the centre.
- USB-C opening: 0.25 mm toward the top (the lid).
These numbers are his hand estimates, not caliper readings (rows V1-*).

Austin sent five of his own photos: IMG_0844 (USB-C end), IMG_0848 (joystick
hole close-up), IMG_0849 and IMG_0852 (assembled case), and IMG_0854 (the
final case on top of the discarded prototypes). They are saved without
metadata in prints/v1.0-photos. They show direction only; no dimension was
taken from them.

The work was done by Claude (Anthropic) in a new session started in this
repository. Codex had stopped partway with a login error. Austin pasted
Codex's session log from this repo, and Claude read only that log, this
repository's files and his photos. Claude did not open any forbidden source,
any other case design, or anything in ~/picowallet. There is no new
third-party geometry. cad/v1_production.py builds on the S2 and S1 sources
in this repository.
## 2026-09-25 — v1.1 USB-end spacer

Austin tested the PETG v1.0 prints (black base, white lid, gray caps). His
words: it "works really well", but the board stack slides left and right
inside the case, and it lines up best pushed fully to the right. He estimates
the play at more than 1 mm, about 1.2 mm, and asked for about 1.2 mm to be
taken out on the joystick's left, in both the base and the lid. Claude asked
which wall he meant, and he chose the USB-C end wall. The CAD model predicts
only 0.6 mm of play; the design follows his physical reading and records the
difference. The spacer is 1.0 mm, so 0.2 mm stays free. The geometry is
original (cad/v1_1_spacer.py), with no outside inputs and no forbidden
sources opened.
## 2026-09-25 — v1.2 half spacer

Austin found that the v1.1 lid spacer is in the right place but too big: the
screen board will not sit flush. He asked for half as much, 0.5 mm.
cad/v1_1_spacer.py gained configure(rev, spacer); the v1.1 STLs regenerate
byte-identical. cad/v1_2_half_spacer.py builds v1.2 with 0.5 mm. There are no
new outside inputs.
## 2026-09-25 — v1.3 short USB end

Austin rejected the spacer approach, because the lip and the base stops meant
reprinting both halves anyway. He asked instead for the USB-C end wall to
move 0.5 mm inward on both halves, making the case shorter. cad/v1_3_short_end.py
rebuilds v1.0 with the end datums (Y1, IY1) moved 0.5 mm. A check shows both
parts are identical to v1.0 for y < 51. The v1.1 and v1.2 spacer designs are
kept as history and are not used. There are no new outside inputs.
## 2026-09-26 — v1.3 promoted to current best

Austin tested the printed v1.3 lid and base: "holds the case just right,
nothing rattles, everything clicks." He named it the best version so far and
asked for a stable reference the print Mac can use for batches.
stl/current/ holds byte copies of the tested v1.3 lid and base, the v1.0 J2
joystick and a button, plus a full-set plate. There is no new geometry.
## 2026-09-26 — v1.4 rounded-edge look trial

Austin asked for a v1.4 with the edges around the LCD and around the top
rounded, and for a 3D render to review before printing.
cad/v1_4_rounded.py fillets the v1.3 lid's top perimeter (1.5 mm) and the LCD
window edge (0.7 mm). It only removes material, and the base and caps are
unchanged. The radii are original choices; there are no outside inputs. The
lid has not been printed.
Same day, review 4: Austin said the screen's black border can be covered, and
asked for the opening to come in "a little bit all the way around". The
window is 1.0 mm smaller per side, a bezel ring sits 0.3 mm above the glass,
and the edge is re-rounded 1.2 mm. These are original choices; the border
width is not measured. A screenshot review caught a 0.15 mm skin that closed
the window in one intermediate build. It was fixed, and a
"window_open_down_to_glass" check now guards it.
## 2026-09-26 — J4 flat-top joystick, v1.4 lid saved

Austin confirmed the v1.4 lid is the direction and asked to save it, then
explained that the joystick has a press-in click that the round ball makes
hard to hit. He asked for a ball that is flat on top. cad/joystick_j4.py cuts
a 5 mm flat pad into J2's ball and softens its rim; the socket and ball
centre are unchanged. Original geometry; there are no outside inputs. It is
shown in the v1.4 viewer and has not been printed.
J4 review 2 (same day): Austin liked the flat and asked for it bigger, with "a
little hat". The ball now narrows to a 5.5 mm waist, flares out at 45° to a
7 mm disc, and ends in a flat top of about 6 mm. The height is back to J2's.
Original geometry.
J4 review 3 (same day): Austin preferred the plain ball and asked for it cut
flat at its widest point, then bigger, "just barely" through the lid hole,
and flat all the way across. The ball is now 7.4 mm, cut through its centre,
with a 0.3 mm edge break. A new check reruns the J1-CHECK tilt scenarios
against the v1.4 lid and fails on any contact J2 did not have. That ruled out
7.6 and 7.5 mm. Original geometry.
Austin approved J4 and sent it to print (gray PETG, drop
20260926-112324-joystick). He also supplied a screenshot of the v1.4 viewer
for the record. It is saved as renders/v1.4/screenshot-2026-09-26.png with
the metadata removed and the pixels unchanged. It is a render of our own
model, not a design input.
J4 socket bug (2026-09-26): Austin's photos showed a messy, non-working J4
socket. Claude found that the bigger ball filled the top 1.5 mm of the square
socket; that was Claude's CAD error, not a print fault. It is fixed by
re-cutting the J2 socket, with a new check that the socket void is identical
to J2. Photos are archived in prints/v1.4-photos.
## 2026-09-26 — J5 press-in room

Austin found that the joystick's centre click works with the cap off but not
with it on. He asked for the socket to narrow sooner so the cap rides higher.
cad/joystick_j5.py shortens the round mouth by LIFT and keeps the 2.0 mm square
grip; the outside is identical to J4. The tilt checks showed that raising the
cap brings the flange closer to the lid, which costs tilt room, so two test
caps are provided (lift 0.3 and 0.5). The fixed J4 file (as sent) is kept as
stl/v1.4/joystick-j4-fixed.stl. Original geometry.
## 2026-09-26 — J6 clean-press test set

Austin: with the cap on, the centre press also triggers a direction, and J5
did not fix it. Claude's reading is that the cap rocks on the stem (2.01
socket on a 1.86 stem) and that off-centre pushes on the wide flat tip the
stick. cad/joystick_j6.py makes three variants: A (1.95 socket), B (1.90) and
C (1.95 plus a thumb dish), marked by 1/2/3 flange notches. Original
geometry; there are no outside inputs.
## 2026-09-26 — J7 printable socket

After the J6 stringing photo, Austin pointed out that his stick measurements
were already in the repo (J4 1.86 stem, J4b 2.94 lip, J6 5.00 tip height).
Claude had not looked first. cad/joystick_j7.py rebuilds the J6 A/B/C sockets
with no flat overhang, a round-to-square 45° funnel and a pyramid roof, and a
check that finds no downward face steeper than 45° inside the socket.
Original geometry.
## 2026-09-26 — J8 variations on J7-B

Austin: B fits best, A is worse, and with B a direction push sometimes also
clicks the centre. He asked for three more like B. cad/joystick_j8.py changes
one thing each: a smaller flange, a smaller flange plus riding higher, or a
rounder top edge. Original geometry.
J9 (2026-09-26): Austin liked J8-3's round edge and B's hole. Claude checked
that they have identical sockets, and made J9 (J8-3 without notches) to print
in triplicate to separate print variation from design. Original geometry.
## 2026-09-26 — v1.4 lid crush ribs

Austin wanted the lid and base to hold together better without reprinting
the bases. Claude proposed crush ribs, and Austin said to take the best guess
and print one lid. There are 12 ribs, 0.15 mm interference, in the lid skirt
only (cad/v1_4_rounded.py). The checks show contact with the base only at the
ribs, and the ribs clear the catches and the pry notch. The earlier no-rib
v1.4 lid STL (SHA 30596150…, printed 2026-09-26) stays in git history at
c2425d0. Original geometry.
## 2026-09-26 — v1.5 taller lid

Austin found that J9 clicks the centre on direction pushes only when the lid
is on, and asked for a slightly taller lid. The CAD tilt check showed the J9
flange reaching the roof underside. cad/v1_5_tall.py stretches the ribbed
v1.4 lid 0.5 mm above the board hold-down. It also thickens the button cap
flanges by 0.5 and rounds the joystick hole edge by 0.6. Austin stopped the
queued ribbed v1.4 lid before it printed. Original geometry; base unchanged.
## 2026-09-26 — v1.5 promoted to current best

Austin tested the v1.5 lid with the printed v1.3 base, J9 and the original
buttons, and said everything works. He asked for this set to be saved as the
latest. The v1.5 button variant was removed (the original S2 caps are used).
stl/current/ holds byte copies of the tested files; cad/current.py checks
each one against its source. Tagged v1.5. There is no new geometry.
## 2026-09-26 — v1.6 smooth top edge

Austin found a rough line at the v1.5 lid's top edge. The cause is Claude's
design: printed face down, the 3 mm fillet starts flat at the bed. v1.6
fills that start to a 45° tangent band (cad/v1_4_rounded.py TOP_BEVEL, built
by cad/v1_6_bevel.py). The rest is v1.5. Two geometry slips (a cut that
removed nothing, and a fill that was too narrow and too deep) were caught by
the checks before any file left. Original geometry.
## 2026-09-27 — v1.7 locking case

Austin: the case opens too easily, so do all three proposals and redesign the
whole case. cad/v1_7_lock.py makes 0.5 mm hooks with a gentler ramp, adds two
end catches (6 total) and keeps only the base half of the pry slot. The lid
is v1.6 with new pockets. The base is v1.3 with new catches. J9 and the
buttons are unchanged. Original geometry; there are no outside inputs.
Same day: Austin reported a rough edge on the button side of the LCD opening.
It is the same face-down overhang as the outer edge. The v1.7 lid now fills
the window and joystick fillet starts to 45° (R.HOLE_BEVEL, T5.JOY_BEVEL).
The v1.7 lid was re-dropped; the base is unchanged. Original geometry.
2026-09-29 J10 joystick set (cad/joystick_j10.py, cad/j10_tilt.py): four
variants on J9 with tabs or a lower ride, Roman numerals engraved on top.
Original geometry from J9 and Austin's report of a double click; no outside
inputs.
2026-09-30 J11 joystick set (cad/joystick_j11.py): J9 with a square flange
(8.0 or 7.2 across the flats, two turns), numerals I-IV. Austin's design
direction; original geometry from J9; no outside inputs. j10_tilt.py now
exposes tilt() for reuse.
2026-09-30 J12 joystick set (cad/joystick_j12.py): J11-III with lift
0.4-0.7, numerals V-VIII. J10.strokes/mark and J11.cap take optional size and
lift arguments; J10 and J11 STLs rebuild byte-identical. Original geometry,
no outside inputs.
2026-09-30 J13 joystick set (cad/joystick_j13.py): J11-III square at lift
0.55-0.70 with the flange thinned under the lid, and two thinned round discs
(8.6, 8.8); bold letters H T L X O E. Original geometry, no outside inputs.
2026-09-30 J14 joystick set (cad/joystick_j14.py): J13-O with square grip
1.85/1.90/1.95, marked 1-3 dots. Original geometry, no outside inputs.
2026-09-30 J15 (cad/joystick_j15.py): J14-2 without dots; now stl/current/joystick.stl. Original geometry.
2026-09-30 J16 (cad/joystick_j16.py): J15 with a square-only socket and four diagonal flares. Original geometry, no outside inputs.
2026-09-30 J17 (cad/joystick_j17.py): five J16 variants, tabs 1.3-2.3x and hole 0-0.2 shallower, dice-dot marks. Original geometry, no outside inputs.
2026-09-30 J18 (cad/joystick_j18.py): J17-B tabs, hole depth 2.2-1.7, dots 1-6; J4c = Austin's ~2 mm tip-to-collar estimate. Original geometry.
2026-09-30 J19 (cad/joystick_j19.py): J18 at depths 1.6-1.2. Original geometry.
2026-09-30 J20 (cad/joystick_j20.py): J19-2 with a 3.2 x 0.5 round mouth and funnel, 1.5 total depth. Original geometry.
2026-09-30 J21 (cad/joystick_j21.py): J20 at depth 1.9 / 2.0, dots 1/2; J20.cap takes depth and dots (J20 STL rebuilds identical). Original geometry.
2026-09-30 J22 (cad/joystick_j22.py): J21-1 without the dot; now stl/current/joystick.stl. Original geometry.

## 2026-10-01 — Jason's Pico pin spacer + I2C variant (fork session)

- By: Claude (Opus 5.5) for Jason McPheron, in his fork, on a branch from
  upstream main (ef8ea69). Seen this session: this repo and Jason's file only.
  No third-party case, no ~/picowallet, no web pages.
- Input: `inputs/2026-10-01-jason-pico-spacer.step`, Jason's original design
  (Onshape "Part Studio 1 - Part 6", exported 2026-10-01T20:06:14Z), SHA256
  8319309b4b510ec4128f9be43da630fcca887caee2540161a71941140802430e. Dimensions
  from his own calipers. Contributed by Jason under the repo's MIT licence;
  committed unchanged as the record. Not third-party geometry.
- Jason's choices: snap the holes to the datasheet grid (P9, P10); extra tabs
  at pins 6 (GP4), 7 (GP5), 36 (3V3), 38 (GND); pin 1 top-right seen from the
  header side (his board); dot + arrow orientation mark.
- What: `cad/pico_pin_spacer.py` rebuilds his file from rows JS-* (checked
  equal to the STEP) and builds the corners and I2C variants on the grid.
  JS-TIGHT (r 0.8 junctions at the 1.78 gaps) and JS-MARK are original.

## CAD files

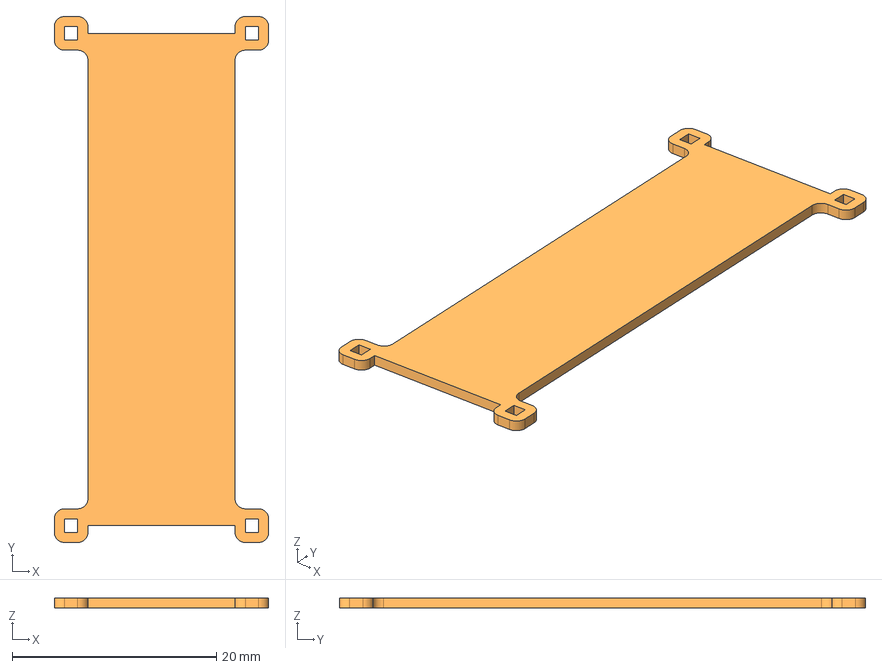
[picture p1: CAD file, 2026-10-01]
inputs/2026-10-01-jason-pico-spacer.step
21.0 x 51.5 x 1.00 mm

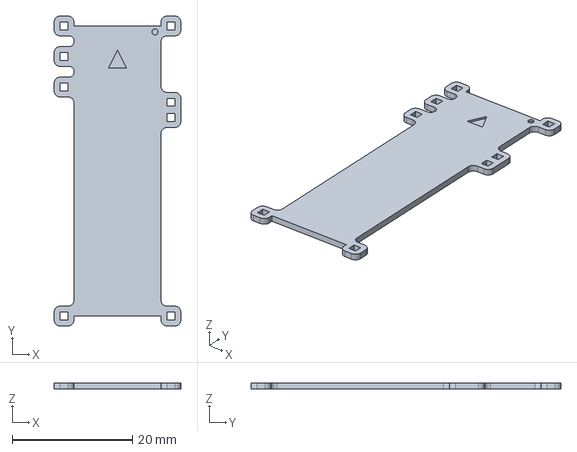
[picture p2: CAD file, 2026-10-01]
renders/pico-spacer/pico-spacer-i2c.step
21.1 x 51.6 x 1.00 mm

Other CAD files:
stl/pico-spacer/pico-spacer-i2c.stl
renders/pico-spacer/pico-spacer-corners.step
stl/pico-spacer/pico-spacer-corners.stl

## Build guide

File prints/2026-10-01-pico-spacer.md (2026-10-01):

# Pico pin spacer — corners and I2C versions

Jason's spacer on the datasheet pin grid. Sits on the header side of the Pico
(toward the LCD) and slips over the pins through 1.3 mm square holes.

- `stl/pico-spacer/pico-spacer-corners.stl` (pins 1, 20, 21, 40), SHA256 `877b27ca257e21082cb70e80f18671b639bcdd7e03f121281bd80db3ca17d7fe`.
- `stl/pico-spacer/pico-spacer-i2c.stl` (+ pins 6, 7, 36, 38), SHA256 `96093fd7afd302894a48cc4968a5d5e7937cf30e24a2287faa25ecc7ca7f8538`.

Flat as exported (Pico side on the bed, dot and arrow up), no supports.
Printer, material and settings: to be filled in by Jason.

Check:
- the I2C version against `renders/pico-spacer/top-view.svg` before fitting:
  dot by pin 1 (GP0), arrow toward USB;
- it drops over all its pins without forcing;
- the LCD still plugs fully onto the Pico (the spacer needs 1.0 free between
  the header plastic and the LCD sockets);
- the case still closes.

## Result

(pending)

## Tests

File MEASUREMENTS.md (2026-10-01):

# Measurements

Every number the design uses lives here first. Rows have an ID. `cad/` cites
the ID. Blank means not measured yet. Units are mm.

Sources: `cal` = caliper on the bench, three readings, photo in
`measurements/` where useful. `ds` = datasheet or drawing, name the document
and page. When cal and ds disagree, write both and say which we use.

## Boards

There are several Pico-footprint boards on the bench and they differ: micro-USB
vs USB-C, connector overhang, component heights, sometimes hole positions. Each
board gets its own scan, its own caliper rows and its own photo set. The case
either fits all of them or has a base per board, decided in `DESIGN.md` once
the numbers are in.

Board register. Add a row when a new board shows up. The tag prefixes its rows
and files (`P2W-P11`, `measurements/P2W-P11-usb-overhang.jpg`).

| Tag | Board | USB | Marking / colour | Chip | Notes |
|---|---|---|---|---|---|
| P2W | Raspberry Pi Pico 2 W, official | micro-USB | green | RP2350 | official Pico 2 STEP applies |
| PINK | USB-C clone, pink | USB-C | pink | RP2040 | no CAD exists, measure everything |
| | | | | | add more here |

## P. Pico-footprint board rows. One copy per board tag.

Datasheet values below are from the Raspberry Pi Pico 2 W datasheet, mechanical
drawing section, and apply to P2W only. Confirm each with calipers. Copy this
table once per tag; clones must not inherit the datasheet numbers.

| ID | Dimension | Value | Source | Notes |
|---|---|---|---|---|
| P1 | Board length | 51.0 | ds Pico 2 W | confirm cal |
| P2 | Board width | 21.0 | ds Pico 2 W | confirm cal |
| P3 | PCB thickness | 1.0 | ds Pico 2 W | confirm cal |
| P4 | Mounting hole diameter | 2.1 | ds Pico 2 W | confirm cal |
| P5 | Hole centre from short edge | 2.0 | ds Pico 2 W | both ends, confirm cal |
| P6 | Hole centre from long edge | 4.8 | ds Pico 2 W | both sides, confirm cal |
| P7 | Hole spacing along length | 47.0 | ds Pico 2 W | P1 minus 2×P5 |
| P8 | Hole spacing across width | 11.4 | ds Pico 2 W | P2 minus 2×P6 |
| P9 | Header pitch | 2.54 | ds Pico 2 W | |
| P10 | Header row spacing | 17.78 | ds Pico 2 W | 7 × 2.54 |
| P11 | Micro-USB overhang past board edge | | cal | |
| P12 | Micro-USB shell width | | cal | |
| P13 | Micro-USB shell height | | cal | |
| P14 | Micro-USB centre offset from board centreline | | cal / ds | |
| P15 | Height of tallest part above PCB, bottom side (component side facing away from LCD) | | cal | wireless module, BOOTSEL |
| P16 | BOOTSEL button position from short edge | | cal | |
| P17 | BOOTSEL button position from long edge | | cal | |
| P18 | Header pin length below PCB when plugged into LCD | | cal | how far the Pico sits from the LCD board |

| P19 | USB connector type | | look | micro-USB or USB-C |
| P20 | Mounting holes present and where | | cal / scan | clones sometimes move or drop them |
| P21 | Flatbed scan of the bottom side, 1200 dpi | | scan | `measurements/<TAG>-scan-bottom.png` |
| P22 | Flatbed scan of the top side, 1200 dpi | | scan | `measurements/<TAG>-scan-top.png` |

### P2W rows: (table above, fill in)

### PINK rows (USB-C clone, pink, RP2040, male headers soldered). All cal, none from a datasheet.

| ID | Dimension | Value | Source | Notes |
|---|---|---|---|---|
| PINK-P1 | Board length | 51.04 | cal 2026-09-24 | scan01 read 50.75 (edge blur); matches the official Pico outline. `measurements/2026-09-24-cal-PINK-P1-board-length-1.jpg` |
| PINK-P2 | Board width | 20.82 | cal 2026-09-24 | scan01 read 20.95 (edge blur). `measurements/2026-09-24-cal-PINK-P2-board-width-1.jpg` |
| PINK-P3 | PCB thickness | 1.23 | cal 2026-09-24 | `measurements/2026-09-24-cal-PINK-P3-pcb-thickness-1.jpg` |
| PINK-P11 | USB-C overhang past board edge | 2.47 | scan01 | shell past the short edge; the scan edge was sharp here (shell sits on the glass). ±0.2 |
| PINK-P12 | USB-C shell width | 8.87 | cal 2026-09-24 | metal shell, wide way. `measurements/2026-09-24-cal-PINK-P12-usbc-width-1.jpg` |
| PINK-P13 | USB-C shell height | 3.08 | cal 2026-09-24 | metal shell, thin way. Shell top is ~2.4 above the PCB (A1), so ~0.7 of it sits in/below the board line. `measurements/2026-09-24-cal-PINK-P13-usbc-height-1.jpg` |
| PINK-P15 | Tallest part above PCB, component side | 3.25 | cal 2026-09-24 | Austin read 4.48 PCB back face to USB-C shell top = the board's full thickness; minus PINK-P3 1.23. Stack check: A1 19.95 − 17.54 = 2.4 (jaws not exactly opposite there); use 3.25. `measurements/2026-09-24-cal-PINK-P15-board-plus-usbc-height-1.jpg` |
| PINK-P18 | Header pin length below PCB | ~10.0 | cal 2026-09-24 | Austin: 10.5 jaw to jaw including the solder tips on the top face; about 10.0 from the underside to the pin tips. The stack (A rows) is the number that matters. `measurements/2026-09-24-cal-PINK-P18-pin-length-1.jpg` |
| PINK-P18b | Header plastic strip thickness | | cal | |
| PINK-P19 | USB connector type | USB-C | look | |

## L. Waveshare Pico-LCD-1.3, board

| ID | Dimension | Value | Source | Notes |
|---|---|---|---|---|
| L1 | Board length | | cal / ds Waveshare drawing | |
| L2 | Board width | | cal / ds | |
| L3 | PCB thickness | 1.97 | cal 2026-09-24 | one reading, `measurements/2026-09-24-cal-L3-lcd-pcb-thickness-1.jpg` |
| L4 | Corner radius of PCB | | cal | |
| L5 | Mounting hole diameter | | cal / ds | |
| L6 | Mounting hole positions, each, from one chosen corner | | cal / ds | list all |
| L7 | Female header socket height above PCB, Pico side | 8.69 | cal 2026-09-24 | sets stack gap. Read 10.66 socket top to PCB front face, minus L3 1.97. `measurements/2026-09-24-cal-L7-lcd-socket-height-1.jpg` |
| L8 | Female header position from edges | | cal / ds | |
| L9 | Tallest part on the Pico side other than headers | | cal | |

### Scan 01 results, LCD top side (2026-09-24). Source `scan01` = `measurements/2026-09-24-scan-01-all-boards-600dpi.jpg`, fit in `2026-09-24-scan-01-analysis.json`, overlay `2026-09-24-scan-01-lcd-top-fit.png`, code `tools/measure_scan.py`

Scale 23.666 px/mm from 196 rule ticks over 196 mm, fit RMS 0.73 px (0.031 mm); nominal 600 dpi would be 23.622. Origin: see "Chosen corner" below. Outline edges are blurred where the board sits off the glass, so outline rows carry ±0.3 mm until calipers confirm; centres of features that touched the glass (plungers, stem, glass) are good to ~0.1 mm.

| ID | Dimension | Value | Source | Notes |
|---|---|---|---|---|
| L1 | Board length (y) | 52.5 | cal 2026-09-24 | scan01 read 52.68 (edge blur +0.18). `measurements/2026-09-24-cal-L1-lcd-board-length-1.jpg` |
| L2 | Board width (x) | 26.44 | cal 2026-09-24 | scan01 read 26.58 (edge blur +0.14). `measurements/2026-09-24-cal-L2-lcd-board-width-1.jpg` |
| S1 | Glass outline length (y) | 26.48 | scan01 | black glass as visible; ±0.2 |
| S2 | Glass outline width (x) | 25.19 | scan01 | ±0.2 |
| S4 | Glass centre x | 13.15 | scan01 | glass spans x 0.56 to 25.75 |
| S5 | Glass centre y | 26.05 | scan01 | glass spans y 12.81 to 39.29 |
| B4 | Plunger diameter | 2.38 × 3.00 | cal 2026-09-24 | oval: 2.38 across x, 3.00 along y. Cap bears on top; the casing (B1/B2) is what the cap must cover. `measurements/2026-09-24-cal-B4-lcd-plunger-long-1.jpg` |
| B8a | Button Y centre (leftmost) x, y | 4.85, 4.14 | scan01 | |
| B8b | Button X centre x, y | 10.58, 4.00 | scan01 | |
| B8c | Button B centre x, y | 16.16, 4.02 | scan01 | |
| B8d | Button A centre (rightmost) x, y | 21.87, 4.12 | scan01 | |
| B8p | Button pitch (labels Y X B A left to right, from the silkscreen in `2026-09-24-cal-B2-lcd-button-body-1.jpg`) | 5.67 | scan01 | mean of the three gaps |
| J4 | Stem diameter at top | 2.41 | scan01 | dark cap only, confirm cal |
| J10 | Joystick centre x, y | 13.24, 46.22 | scan01 | stem top; base centre agrees within 0.4 |
| J1/J2 | Joystick base plan size | 8.81 × 7.22 | scan01 | fitted to the silver diamond, blurred; confirm cal |

Not from this scan: every Z (L3, L7, L9, S3, B3, B5, B6, J3, J6-J9), hole rows L5/L6 (none visible from the top; back side scan was out of focus), and the switch bodies B1/B2 (blurred).

## S. Screen

| ID | Dimension | Value | Source | Notes |
|---|---|---|---|---|
| S1 | Glass outline length | | cal | |
| S2 | Glass outline width | | cal | |
| S3 | Glass top height above PCB | 2.05 | cal 2026-09-24 | read 12.71 socket top to glass top, minus L3+L7 10.66. Whole hat, socket top to glass top = 12.71. `measurements/2026-09-24-cal-S3-lcd-glass-height-1.jpg` |
| S4 | Glass position from chosen corner, x | | cal | |
| S5 | Glass position from chosen corner, y | | cal | |
| S6 | Active area length | | cal / ds | |
| S7 | Active area width | | cal / ds | |
| S8 | Active area offset within glass, x | | cal | |
| S9 | Active area offset within glass, y | | cal | |
| S10 | Flex cable location and width | | cal | so the lid does not pinch it |
| F1 | Blue tape past the right PCB edge | ~4.0 out, y 22 to 30, at glass level | scan01 | soft edges. In the scan it lies on top of the glass and runs off the edge: probably the screen protector's pull tab, not part of the board. Ask Austin |

## B. Buttons, four tact switches

Measure the switch, not a cap. Identify the part if you can from the marking or
the schematic and add its datasheet to `SOURCES.md`.

| ID | Dimension | Value | Source | Notes |
|---|---|---|---|---|
| B1 | Switch body length | 3.34 | cal 2026-09-24 | metal casing, measured in y (toward the glass). `measurements/2026-09-24-cal-B1-lcd-button-body-1.jpg` |
| B2 | Switch body width | 4.42, 4.30 | cal 2026-09-24 | metal casing, two readings (feet may add to the first); the other plan axis from B1. `measurements/2026-09-24-cal-B2-lcd-button-body-{1,2}.jpg` |
| B3 | Switch body height above PCB | 1.81 | cal 2026-09-24 | Austin read 12.47 socket top to metal casing top, minus 10.66. Oval top (B5 2.61) is 0.80 proud of the casing. `measurements/2026-09-24-cal-B3-lcd-button-casing-height-1.jpg` |
| B4 | Plunger diameter | | cal | |
| B5 | Plunger top height above PCB, at rest | 2.61 | cal 2026-09-24 | Austin read 13.27 socket top to button top, minus L3+L7 10.66. `measurements/2026-09-24-cal-B5-lcd-button-height-1.jpg` |
| B6 | Plunger travel | 0.38 | cal 2026-09-24 | Austin read 12.89 socket top to oval held pressed = 2.23 above PCB; rest is 2.61. `measurements/2026-09-24-cal-B6-lcd-button-pressed-1.jpg` |
| B7 | Plunger shape | oval | look 2026-09-24 | light-coloured oval top; 2.38 across the narrow way (cal), about 2.6 long (scan01) |
| B8 | Centre of each switch from chosen corner, x, y | | cal / ds | four rows, name them by silkscreen label |
| B9 | Actuation force | | ds | for cap weight and return |

## J. Joystick

| ID | Dimension | Value | Source | Notes |
|---|---|---|---|---|
| J1 | Body length | | cal | |
| J2 | Body width | | cal | |
| J3 | Body height above PCB | | cal | |
| J4 | Stem diameter at top | 1.86 | cal 2026-09-24 | across the flats; square section. A cap grips this. A short lip at the very base is 2.94 wide (J4b, cal) — not part of the stick, the cap must clear it |
| J4b | Lip at the stem base, width | 2.94 | cal 2026-09-24 | no photo saved |
| J5 | Stem shape | square | look 2026-09-24 | 1.86 square at the tip, wider at the base |
| J6 | Stem top height above PCB, centred | 5.00 | cal 2026-09-24 | Austin read 15.66 socket top to stem tip, minus L3+L7 10.66. `measurements/2026-09-24-cal-J6-lcd-joystick-height-1.jpg` |
| J7 | Stem tilt angle, full deflection | | cal / ds | |
| J8 | Stem top travel at full deflection, horizontal | | cal | |
| J9 | Centre press travel | | cal / ds | |
| J10 | Centre from chosen corner, x, y | | cal / ds | |
| J11 | Clearance around stem before it hits the body or nearby parts | | cal | |

## A. Assembled stack

| ID | Dimension | Value | Source | Notes |
|---|---|---|---|---|
One block per board tag. The hat is the same; the Pico under it changes.

| ID | Dimension | Value | Source | Notes |
|---|---|---|---|---|
| A1 | Total stack height, Pico bottom-most part to glass top | PINK: 19.95 (glass to USB-C shell); 17.54 glass to the Pico PCB back face | cal 2026-09-24 | Austin: 19.95 is "very close" — jaws not exactly opposite because the plug and glass are at different spots; take as ±0.2. So the USB-C shell stands ~2.4 above the Pico PCB. `measurements/2026-09-24-cal-PINK-A1-stack-glass-to-usbc-1.jpg`, `...-pcb-back-{1,2}.jpg` |
| A2 | Gap between Pico PCB top and LCD PCB bottom | PINK: 12.29 | derived 2026-09-24 | 17.54 − S3 2.05 − L3 1.97 − PINK-P3 1.23. Socket is 8.69 of that; the male header plastic + standoff is the other 3.6 |
| A3 | Pico USB position relative to LCD board edges | joystick end, centred in x (assumed) | Austin 2026-09-24 | USB-C pokes out at the joystick end. x-centring not measured yet |
| A4 | Anything sticking out past the LCD board outline | | look | per tag |

## T. Print tolerances, filled in during Phase 3

| ID | Dimension | Value | Source | Notes |
|---|---|---|---|---|
| T1 | Hole clearance for a free fit | | print | |
| T2 | Clearance for a snug slide | | print | |
| T3 | Cap-to-hole radial clearance | | print | |
| T4 | Printer and nozzle | | | |
| T5 | Material | | | |

## Chosen corner

State here which corner of the LCD board is the origin for all x, y values,
looking at the screen, and which direction is +x and +y. Use the same origin in
`cad/params.py`.

Origin (chosen 2026-09-24): looking at the screen with the joystick at the top
and the four buttons at the bottom, the FPC tape is on the right. Origin is
the bottom-left corner of the LCD PCB. +x to the right (26.44 wide), +y up
toward the joystick (52.50 long, after calipers). The 600 dpi scan is not mirrored (the
rule's digits and the Pico's silkscreen read correctly), so scan x, y map
straight onto this frame.

## R4 audit: derived coordinates and evidence limits

The scan's absolute corner coordinates above used its blurred 26.5835 ×
52.6773 outline. CAD preserves offsets from the fitted board centre and
uses the caliper outline. These are a registration assumption, not new
caliper readings. Do not scale feature spacing to fit the caliper outline.

| ID | Dimension | Value | Source / limitation |
|---|---|---|---|
| SC1 | Glass centre offset x, y | -0.1393, -0.2905 | scan01 JSON glass_centre_uv, reordered v,u |
| BC1 | Button centre offsets x, y, Y/X/B/A | (-8.4400,-22.1949), (-2.7159,-22.3382), (2.8723,-22.3153), (8.5746,-22.2187) | scan01 plungers_uv, reordered v,u; retain individual y values |
| JC1 | Stem centre offset x, y | -0.0529, 19.8792 | scan01 joystick_stem_uv |
| JC2 | Silver base centre offset x, y | 0.2730, 19.4936 | scan01 joystick_base_centre_uv; blurred; differs from stem by 0.505 mm |
| H1 | Header body width/length | 2.54 / 50.8 | provisional render envelope from P9 × 1 / 20; actual plastic and solder envelope unmeasured |
| H2 | Pico corner radius / USB inward depth | 1.0 / 7.0 | inherited render assumptions, not measurements |
| H3 | Silver base orientation / height | 45 degrees / 3.0 | inherited render assumptions, not measurements |
| H4 | PCB corner radius | 1.5 | inherited render only; collision checks also use a sharp rectangle |
| H5 | Blue flag thickness / inboard overlap | 0.3 / 1.0 | inherited illustrative envelope; identity unresolved |

Photo audit: L3's frame shows no board or caliper; S3 and B6 miss the
measurement contact; L7's frame is not a reliable picture of the recorded
10.66 datum. B4's display appears 3.06 rather than recorded 3.00; B2's second
display appears 4.31 rather than 4.30. A1 photos do not unambiguously show
glass contact, so A2 inherits a datum uncertainty as well as the known USB
0.84 discrepancy. PINK-P11 comes from a segmentation that also reports a
20.95-mm USB width (inconsistent with P12 8.87); its ±0.2 claim is not
independently established. Retain all original readings pending recheck.

### R4 design choices (not hardware measurements)

| ID | Choices in mm unless stated | Rationale |
|---|---|---|
| D4-FIT | mating gap 0.20; skirt 0.80; wall 2.20; bump 0.45 × 4 × 1; flexible band span 14; slot 0.60; band roof z=-0.30 | maintain 1.20 tongue; outward flex/release access; bands anchored at both ends to bridge when printed inverted |
| D4-SUPPORT | shelf bearing thickness 0.80, 45-degree underside; pad 1.60, inset 0.50, gap 0.05; shelf gap 0; pocket radius 0.50 | slope from wall to shelf tip; four pads land above side shelves outside switches; sharp corner sensitivity |
| D4-BUTTON | flange 5.00; pocket margin 0.30 | avoid neighbouring flanges colliding when each cap slides sideways by 0.25; no overtravel stop until casing and PCB landing areas are confirmed |
| D4-USB | channel clearance 0.25 for lid fin; shell opening square corners; inherited plug trial 12.5 × 7, recess 1.0 | square envelope contains both rectangular shell bounds; insertion straight down |
| D4-JOY | socket total clearance 0.05 (samples 0, 0.10, 0.20); tip clearance 0; engagement 1.20; disc gap 1.80; hole 12.80; disc 14.0 | seat cap on stem, improve tilt/press room over assumed body and base offset clearance; fit samples are provisional |
| D4-CAD | boolean overlap 0.01; cutter extension 1; bump overlap 0.20; window end clearance 0.30; cavity radius 0.50; window/pocket radius 0.80; plug recess radius 1.0 | construction choices, not hardware facts |
| V4 | joystick sensitivity 10 degrees tilt, 0.30 press, pivot z=0 and 3; XY placement sensitivity 0.10; cap travel sampling 9 positions; insertion sampling 1 mm | diagnostic scenarios only; J7/J9 remain unmeasured |

## R5 user feedback and original choices

Austin reports from the first physical print: joystick must be installed on
the board before the lid and retained by a lower lip; upper control should
be shaft and ball. Also requests a pry notch because the case is hard to
open. No new hardware dimensions supplied. Existing J rows still apply.

| ID | Choices in mm unless stated | Rationale |
|---|---|---|
| D5-JOY | shaft Ø4.20; retaining flange Ø10.40, bottom z=5.00, thickness 0.80; ball Ø7.00, centre z=11.40; throat Ø8.80; flange pocket Ø13.00, ceiling z=6.80; collar outside Ø15.80, roof 1.20 | ball passes opening from inside while wider lip is retained; raised collar clears lip's assumed tilt; socket and engagement inherited from R4 |
| D5-PRY | two side notches centred at y=L1/2, width 6.0 along y, height 1.60, depth 1.0 from exterior, radius 0.50; z centre=-TONGUE_H | gives tool access across skirt/base seam; retains 1.20 of wall behind notch, away from boards |
| V5 | sample press 0 and 0.30, pivots 0 and 3, tilt 0/5/10 degrees; cap pull-up 1.05; assembly clearance with vertical swept envelopes; tool tip 4.0 × 0.60, depth 0.70 | test scenarios, not measured joystick specs or opening-force guarantees |

### V2 print candidate / R5 completed choices

### V3 review choices — 2026-09-25

### V3 low-lid experiment — D7, 2026-09-25

### D8 rear-tab experiment

### J1 isolated round-lip test — 2026-09-25

### V3-FIT fitted shell — 2026-09-25

### V3-FLAT correction — 2026-09-25

### J2 stepped socket trial — 2026-09-25

| ID | Value | Source / limitation |
|---|---|---|
| J2-COLLAR-H | less than1 mm | Austin's direct report after asking collar-only height; not PCB-to-collar height |
| J2-SOCKET | Ø3.00 round opening depth1.00, then2.01 square depth2.00; total3.00 from cap underside | Austin's explicit trial dimensions; square width inherited J1. No extra clearance. IMG_0823 shows3.32 mm on caliper but feature unconfirmed; fit not guaranteed |
| J2-OUTER | identical J1 exterior; blind roof becomes localz3.00 instead of1.90; possible1.10 deeper seating if collar/body allow | Original derived geometry, not measured achievable travel. Do not lower lid until fitted; print flange-down as J1 |

### V3-FLAT parameters

| ID | Choice | Basis |
|---|---|---|
| V3-FLAT | uniform outer facez5.1; underside joystick roof4.4 unchanged; face-down print, rotate180degrees aroundX then translate bedz0; no supports/raft | Austin explicitly approves whole-face raise to fix print orientation. Existing J1 clearance, not new hardware measurement. Screen depth3.05 mm accepted provisionally; unchanged V2 button protrusion1.3 mm, .92 at full press |

### V3-FIT parameters (historical upright print)

| ID | Original design choice | Basis / limitation |
|---|---|---|
| V3-FIT-LID | screen side rails z3.05, local joystick roof4.4..5.1, holeØ8, pocketØ13, outer local bossØ15.8 clipped at screen window; inner pocket clipped window+.4, continuous .4 front wall; button-end top4.6, region ends pocketYmax+.8 | Retain J1's hand-held tested hole/height and V2 buttons; no universal lid-height raise. Local joystick front wall meets upper screen edge, so that small edge segment is higher than side rails. Boss shell dimensions inherited D5/D6; upright print to avoid floating skirt under face-down boss |
| V3-FIT-BUTTON | existing flange z2.61..3.41, pocket ceiling3.56, tops6.4, original4.2×5.4 posts | Exact V2 printed cap parameters; no new caps. V3 low D7 side-wing caps were never printed and must NOT be used |
| V3-FIT-PADS | extend original1.6 square corner pads outward to inner walls, top2.36, bottom.05 | Join pads to shell from first printed pad layer; small corner overhangs still require slicer review |
| V3-FIT-PRINT | both shells upright, bedz0, separation5; PLA .16,3 walls, no supports/raft | Original print plan; actual slice must be checked before start. Lid bottom skirt supplies bed contact, not the raised joystick face |
| V3-FIT-CHECK | inherited0/5/10degree, pivots0/3, press0/.3,8directions; lid-install lifts0..12 in .5 increments; seating shifts0/-.3; mesh tolerance.02/angular.1 | Hypotheses not hardware measurements; compare against J1 to prevent hiding new interference. Additional guessed-body contact reported separately |

### J1 isolated round-lip test parameters

| ID | Choice (mm) | Source / limitation |
|---|---|---|
| J1-CAP | socket 2.01 square, roof5.30, neck Ø5, bottom3.40; flange Ø10.4 × .4 at3.40; ball Ø7 centre8.5 | Original D6-SOCKET baseline; flange and shorter ball are original trial choices, not measurements |
| J1-LID | round hole Ø8, outer disk Ø20, underside4.4, thickness.7; two feet x=±9, width2, y length6, PCB contactz0 | Original hand-held test gauge, not production lid. Local top5.1 =3.05 above glass; surrounding production lid remains undecided. Feet establish height on bare PCB beside joystick; fit needs checking |
| J1-CHECK | tilt0/5/10 degrees; pivotsz0/3; press0/.3; eight compass directions | Stress scenarios only, not measured travel. Preserve failures in report. Print mesh tolerance .02, angular .1; separation5 on plate |
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
